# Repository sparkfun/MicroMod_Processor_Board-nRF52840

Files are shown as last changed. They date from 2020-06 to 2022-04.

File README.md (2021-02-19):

SparkFun MicroMod Processor - nRF52840
========================================

SparkFun MicroMod Processor - nRF52840 (https://www.sparkfun.com/products/16984)

[*SparkFun MicroMod Processor - nRF52840 (DEV-16984)*](https://www.sparkfun.com/products/16984)

Featuring the nRF52840 SoC from Nordic Semiconductor, the SparkFun MicroMod nRF52840 Processor offers a powerful combination of ARM Cortex-M4 CPU and 2.4 GHz Bluetooth transceiver in the MicroMod form-factor with the M.2 MicroMod connector to allow you to plug in a compatible MicroMod Carrier Board in the [MicroMod Ecosystem](https://www.sparkfun.com/micromod). 

The nRF52840 module includes a BT 5.1 stack and supports Bluetooth 5, Bluetooth mesh, IEEE 802.15.4 (Zigbee & Thread) and 2.4Ghz RF wireless protocols (including Nordic's proprietary RF protocol) allowing you to pick which option works best for your application. 

Repository Contents
-------------------

* **/Hardware** - Eagle design files (.brd, .sch)
* **/SF_MM_nRF52840_PB** - Board variant files for Arduino mbed Core.
* **/TestSketches** - Related software for the MicroMod nRF52840 Processor

Documentation
--------------

* **[Hookup Guide](https://learn.sparkfun.com/tutorials/micromod-nrf52840-processor-hookup-guide)** - Basic hookup guide for the MicroMod Processor - nRF52840.
* **[Getting Started with MicroMod](https://learn.sparkfun.com/tutorials/getting-started-with-micromod)** - A tutorial to help you get started with the MicroMod Ecosystem. 
* **[Designing with MicroMod](https://learn.sparkfun.com/tutorials/designing-with-micromod)** - A tutorial to walk you through the specs of the MicroMod processor and carrier board as well as the basics of incorporating the MicroMod form factor into your own PCB designs.
* **[SparkFun Graphical Datasheets](https://github.com/sparkfun/Graphical_Datasheets)** -Graphical Datasheets for various SparkFun products.

License Information
-------------------

This product is _**open source**_! 

Please review the LICENSE.md file for license information. 

If you have any questions or concerns on licensing, please contact technical support on our [SparkFun forums](https://forum.sparkfun.com/viewforum.php?f=152).

Distributed as-is; no warranty is given.

- Your friends at SparkFun.

_<COLLABORATION CREDIT>_

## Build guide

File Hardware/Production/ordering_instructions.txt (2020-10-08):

panel size, 194x70mm
PCB thickness, 0.8mm
number of layers, 4
soldermask color, Red
silkscreen color, White
oz copper, 1oz
finish, ENIG
stencils, top+bottom
pcs per panel, 16
min trace width, 0.1016mm / 0.0040in
min drill size, 0.2000mm / 0.0079in
filename to layer stackup 1/2/3/4: GTL, GL2, GL3, GBL

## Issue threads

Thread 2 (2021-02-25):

Fix ble_temp example

adamgarbo, 2021-02-25:
Hi folks,

A quick heads up that the "ble_temp" example is missing `Wire.begin();`. This prevents the I2C bus/BME280 from initializing and causes the code to freeze after the BLE is initialized. Once added, the code works as intended.

Related forum post: https://forum.sparkfun.com/viewtopic.php?f=182&t=55165

Cheers,
Adam

AndyEngland521, 2021-02-25:
Good catch @adamgarbo

Closed 2021-02-25.

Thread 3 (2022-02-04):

Arduino pin definition compatibility with MicroMod generic pin names

santaimpersonator, 2022-02-04:
Currently, the instructions in the hookup guide don't take into account for the generic pin names of the MicroMod system. For example, the pin names `G0` and  `D0` don't compile in the Arduino IDE.

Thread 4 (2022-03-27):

in correct boards.txt fot softfp

paulvha, 2022-03-27:
When compiling sketch like
```
void setup() {
  // put your setup code here, to run once:
  Serial.begin(115200);
  Serial.print("hallo");

}

void loop() {
  // put your main code here, to run repeatedly:

}
```

you get an error message :
```
arm-none-eabi-g++: error: softfp: No such file or directory
arm-none-eabi-g++: error: fpv4-sp-d16: No such file or directory
exit status 1
Error compiling for board SparkFun MicroMod nRF52840 Processor Board.
```
**Root cause on Mbed Arduino library 2.80, with the compiler arm-none-eabi-gcc-7-2017q4, is the incorrect definition for floating-point.**

You need to change in the boards.txt the definition from

```
sfnrf52840pb.build.fpu=fpv4-sp-d16
sfnrf52840pb.build.float-abi=softfp
```
to
```
sfnrf52840pb.build.fpu=-mfpu=fpv4-sp-d16
sfnrf52840pb.build.float-abi=-mfloat-abi=softfp
```
regards,
Paul

makin-stuff, 2022-04-07:
boards.txt and SF_MM_nRF52840_PB files updated.

Closed 2022-04-07.

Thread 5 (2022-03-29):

more changes needed to compile on version 3.0

paulvha, 2022-03-29:
Compiling the MM nRF52840 will fail on Arduino library version 3.0.

Not only the softfp errors, as mentioned in the other issue, but also other errors. This Sparkfun add-in for the MBED-nano library needs to be updated

see https://forum.sparkfun.com/viewtopic.php?f=182&t=57407&p=232189#p232189 for details and changes to be made

regards,
Paul

makin-stuff, 2022-03-29:
Hi there @paulvha. Thank you for updating us. I will look into these issues with the mbed core sometime this week.

paulvha, 2022-03-30:
Thanks. The issues are not caused by Mbed, They are caused by changes in the Arduino Library folder structure and new  paramaters.
regards,
Paul

makin-stuff, 2022-04-07:
Hi there @paulvha .

I've updated the boards.txt and SF_MM_nRF52840_PB files like you've outlined in the forum post to be compatible with the "Arduino Mbed OS Nano Boards" v3.0.1. I've tested these changes on my personal hardware.

 I'm closing this issue for now, but if you try these files out and they don't work for some reason, please open up another issue on this repo. I will work to get the documentation associated with this product updated as well.

Thanks!

Closed 2022-04-07.

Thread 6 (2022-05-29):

ArduinoBLE fails to compile on nrf52480

paulvha, 2022-05-29:
Based on a post on the SparkFun forum https://forum.sparkfun.com/viewtopic.php?f=182&t=57779, I looked into this problem.

**Error description**
Any ArduinoBLE example (e.g. Batterymonitor) will fail as it can not find references to certain routines.

C:\Users\hk\AppData\Local\Temp\arduino_build_501413\libraries\ArduinoBLE-1.2.2\utility\HCICordioTransport.cpp.o: In function `HCICordioTransportClass::end()':
C:\Users\hk\Documents\Arduino\libraries\ArduinoBLE-1.2.2\src\utility/HCICordioTransport.cpp:237: undefined reference to `ble::CordioHCIDriver::terminate()'
C:\Users\hk\AppData\Local\Temp\arduino_build_501413\libraries\ArduinoBLE-1.2.2\utility\HCICordioTransport.cpp.o: In function `HCICordioTransportClass::begin()':
C:\Users\hk\Documents\Arduino\libraries\ArduinoBLE-1.2.2\src\utility/HCICordioTransport.cpp:215: undefined reference to `ble::CordioHCIDriver::initialize()'
C:\Users\hk\Documents\Arduino\libraries\ArduinoBLE-1.2.2\src\utility/HCICordioTransport.cpp:69: undefined reference to `ble::CordioHCITransportDriver::set_data_received_handler(void (*)(unsigned char*, unsigned char))'

**Root cause**

The libmbed.a  that Sparkfun provides with the variant is using the OLD namespace definition for BLE. The BLE namespace has structure has changed starting Mbed 6.2.1. Arduino is using an Mbed 6 later version than 6.2.1

**Solution**

In the Mbed files in 6.2.0 or before:
CordioHCIDriver.cpp
CordioHCIDriver.h
CordioHCITransportDriver.h
CordioHCITransportDriver.cpp

These files are located  in the folder : mbed-os/features/FEATURE_BLE/targets/TARGET_CORDIO/driver

The namespace definition needs to be changed from :

```
namespace ble {
namespace vendor {
namespace cordio {
```
to

`namespace ble {`

Next to that it will need changes in different files for the nrf52480 Bluetooth target for using the right namespaces : e.g.

using namespace ble::vendor::ambiq_micro;
using namespace ble::vendor::cordio;

A new libmbed.a needs to be created and provided. This will apply to all the nrf52480 that are add-on to the Arduino Nano-Mbed.

Just a thought:
Given that Arduino is making regular changes to their Nano-mbed library and it is hard to keep up with that, wouldn't it be better to take the same approach as Artemis/Apollo3 and provide a single complete library package with Mbed where Sparkfun controls the all the changes?

regards,
Paul

makin-stuff, 2022-06-09:
Hi there @paulvha. Thank you for reporting this problem on our repo. Good catch with the Arduino boards update!

The libmbed.a file is a copy from the "ARDUINO_NANO33BLE" variant. We've updated the [hookup guide](https://learn.sparkfun.com/tutorials/micromod-nrf52840-processor-hookup-guide/arduino-software-setup) to advise customers to duplicate that folder, rename it, and then copy over the unique files from this repo (variant.cpp, pins_ardhuino.h, and boards.txt) in hopes that this would mitigate compilation errors as the arduino package gets updated.

Unfortunately, at this time there is no planned effort to support the MM nRF52840 PB in the same manner we support the Artemis module.

Thanks again for your time and effort!

Closed 2022-06-09.

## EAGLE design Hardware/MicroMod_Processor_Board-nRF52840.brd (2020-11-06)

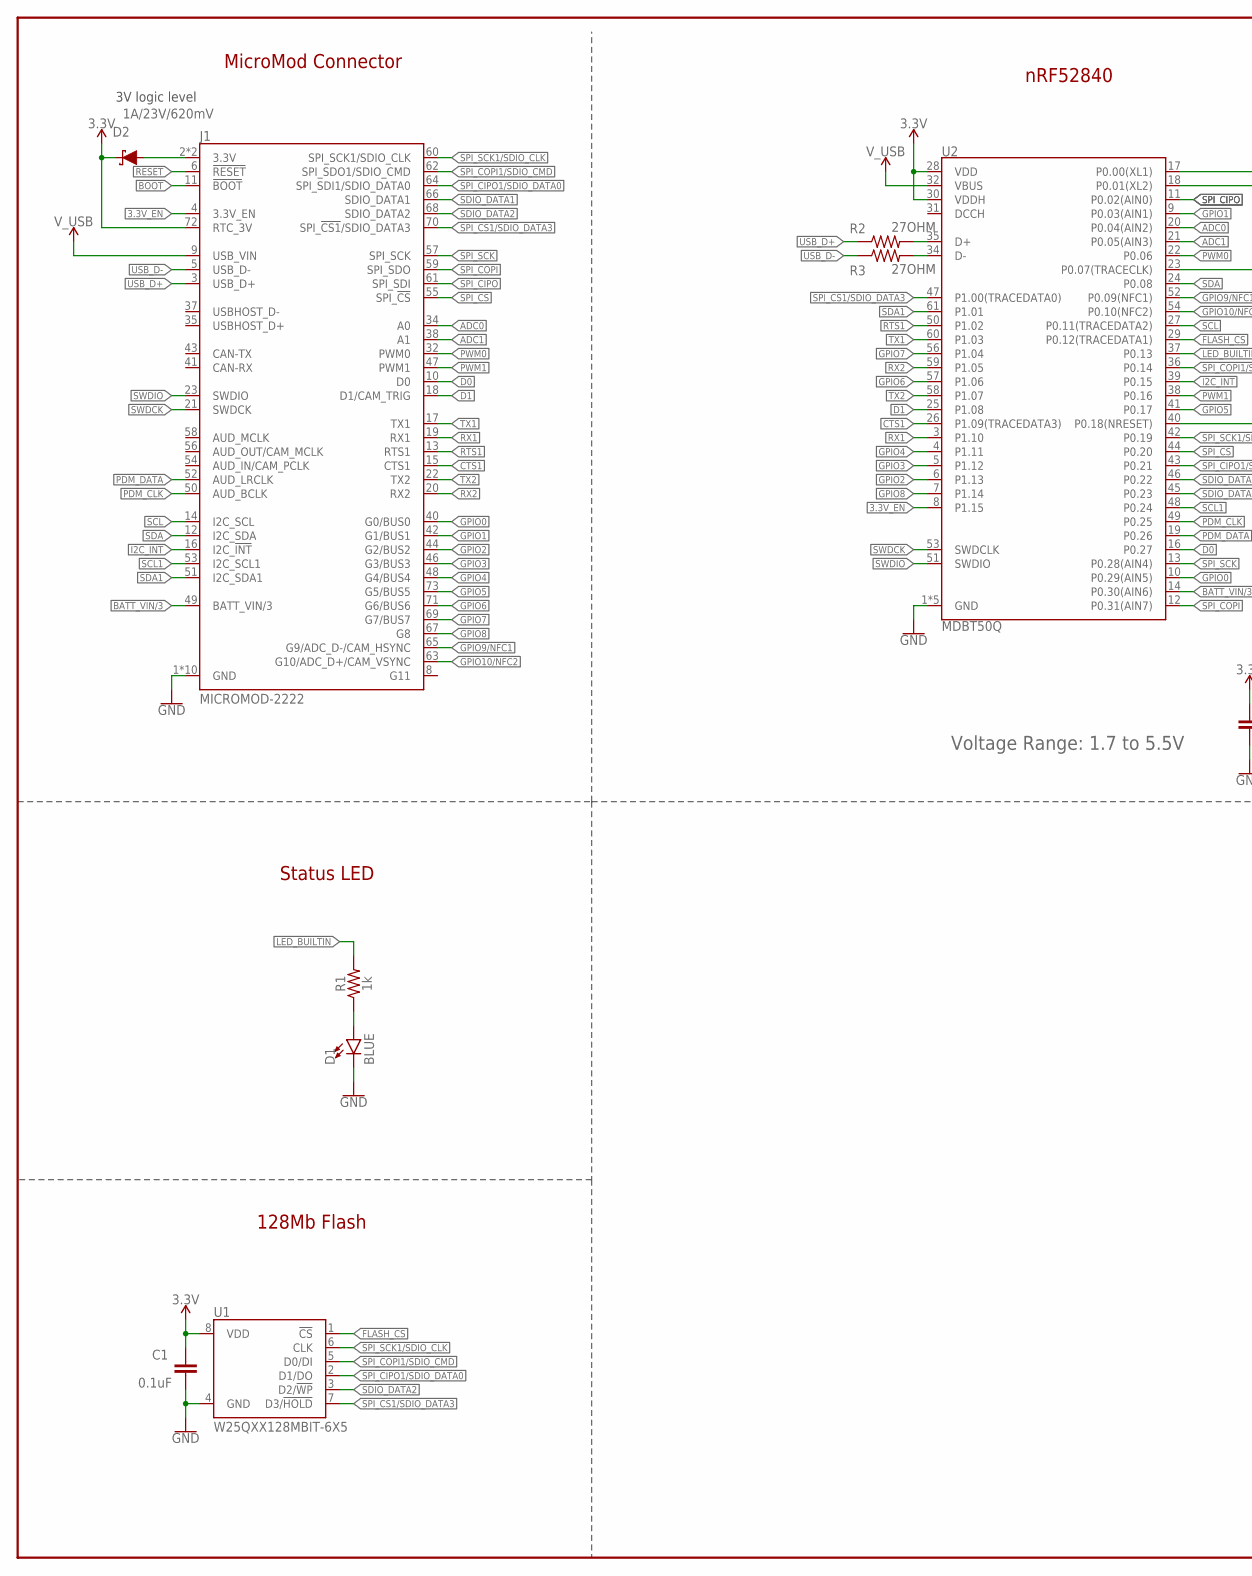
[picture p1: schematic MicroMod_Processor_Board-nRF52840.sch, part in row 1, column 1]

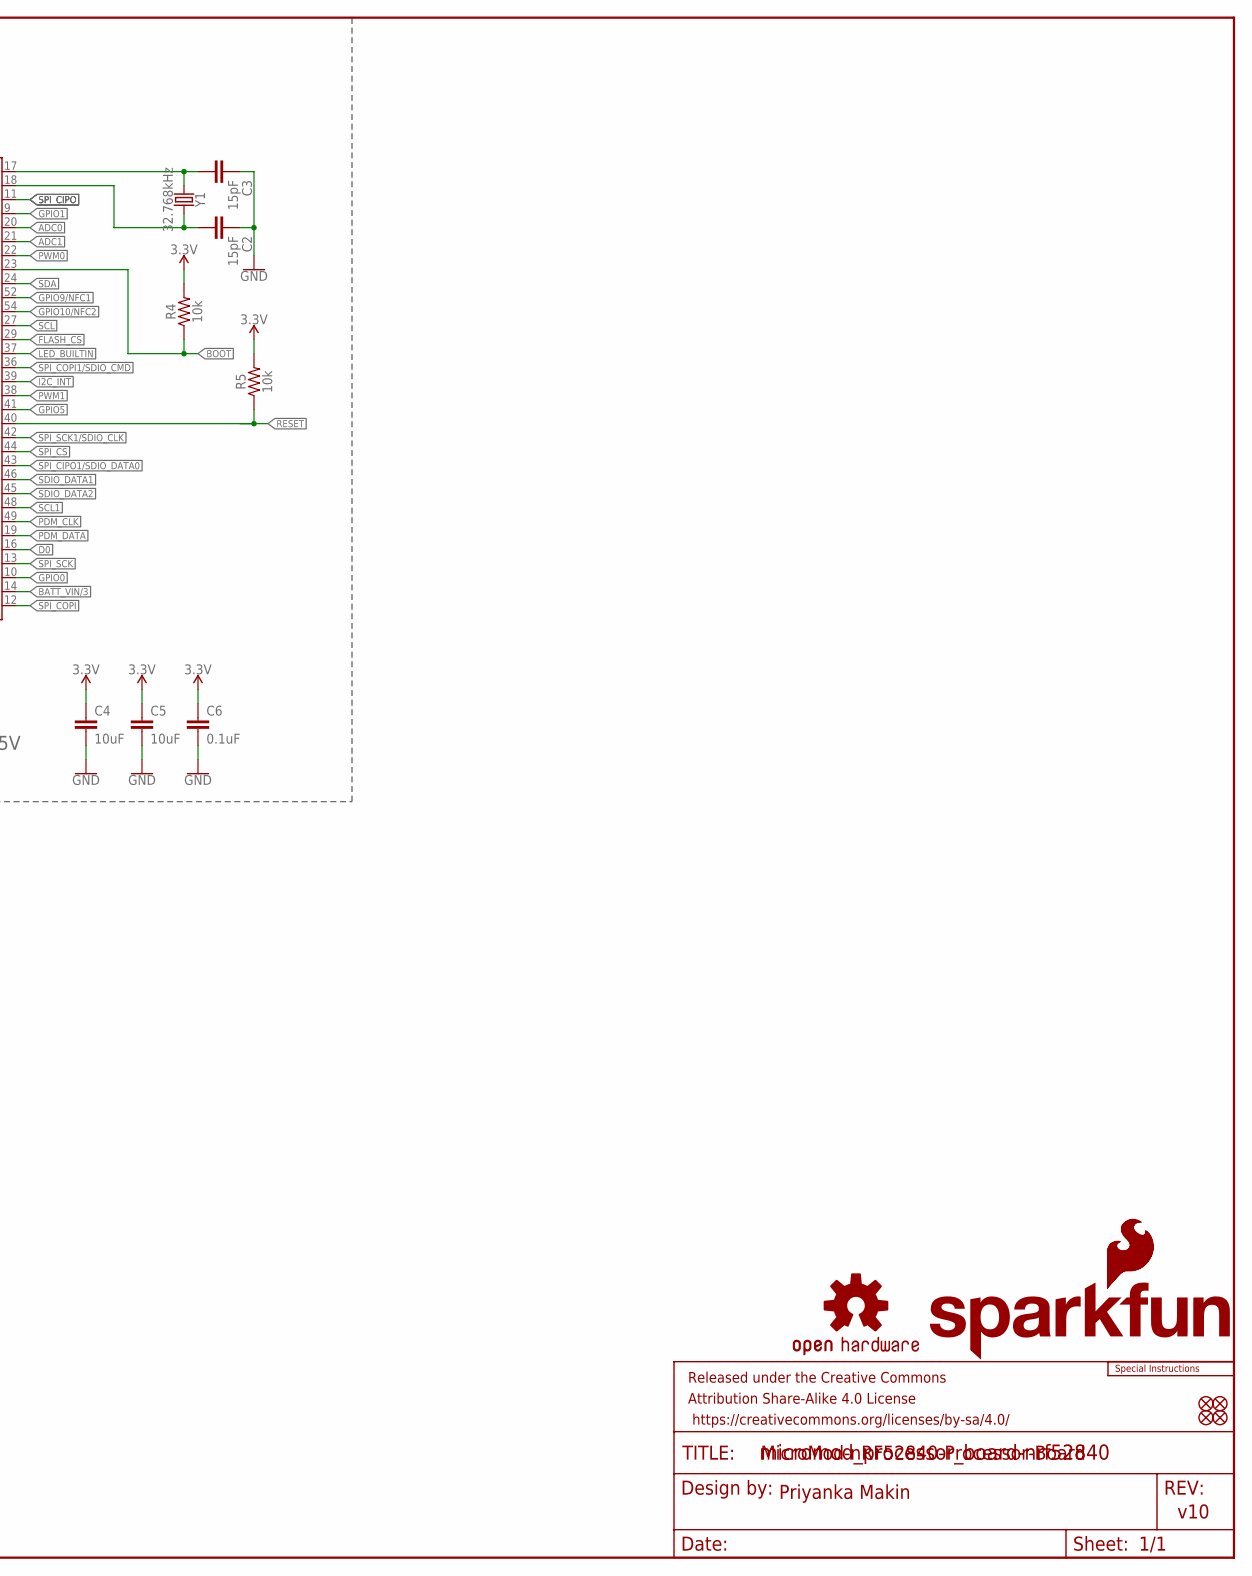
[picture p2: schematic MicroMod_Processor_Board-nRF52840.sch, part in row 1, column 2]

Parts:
C1, C6: 0.1uF; 0402-TIGHT
C2, C3: 15pF; 0402-TIGHT
C4, C5: 10uF; 0402-TIGHT
D1: BLUE; LED-0603
D2: 1A/23V/620mV; SOD-323
FD1, FD2, FD3, FD4: FIDUCIALUFIDUCIAL; FIDUCIAL-MICRO
FRAME1: FRAME-LEDGER; CREATIVE_COMMONS
J1: MICROMOD-2222; M.2-CARD-E-22
LOGO1: SFE_LOGO_NAME_FLAME.1_INCH; SFE_LOGO_NAME_FLAME_.1
LOGO2: SFE_LOGO_FLAME.1_INCH; SFE_LOGO_FLAME_.1
LOGO3: OSHW-LOGOMINI; OSHW-LOGO-MINI
LOGO4: SPECIAL_INSTRUCTIONS-ORDERING; ORDERING_INSTRUCTIONS
R1: 1k; 0402-TIGHT
R2, R3: 27OHM; 0402-TIGHT
R4, R5: 10k; 0402-TIGHT
U1: W25QXX128MBIT-6X5; WSON-8-6X5
U2: MDBT50Q
Y1: 32.768kHz; CRYSTAL-SMD-3.2X1.5MM

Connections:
3.3V: C1.1, C4.1, C5.1, C6.1, D2.C, J1.72 (RTC_3V), R4.2, R5.2, U1.8 (VDD), U2.28 (VDD), U2.30 (VDDH)
3.3V_EN: J1.4 (3.3V_EN), U2.8 (P1.15)
!BOOT!: J1.11 (!BOOT!), R4.1, U2.23 (P0.07(TRACECLK))
!RESET!: J1.6 (!RESET!), R5.1, U2.40 (P0.18(NRESET))
ADC0: J1.34 (A0), U2.20 (P0.04(AIN2))
ADC1: J1.38 (A1), U2.21 (P0.05(AIN3))
BATT_VIN/3: J1.49 (BATT_VIN/3), U2.14 (P0.30(AIN6))
CTS1: J1.15 (CTS1), U2.26 (P1.09(TRACEDATA3))
D0: J1.10 (D0), U2.16 (P0.27)
D1: J1.18 (D1/CAM_TRIG), U2.25 (P1.08)
FLASH_!CS!: U1.1 (!CS!), U2.29 (P0.12(TRACEDATA1))
GND: C1.2, C2.1, C3.1, C4.2, C5.2, C6.2, D1.C, J1.1 (GND), J1.7 (GND), J1.33 (GND), J1.36 (GND), J1.39 (GND), J1.45 (GND), J1.75 (GND), J1.GND1 (GND), J1.GND2 (GND), J1.GND3 (GND), U1.4 (GND), U2.1 (GND), U2.2 (GND), U2.15 (GND), U2.33 (GND), U2.55 (GND)
GPIO0: J1.40 (G0/BUS0), U2.10 (P0.29(AIN5))
GPIO1: J1.42 (G1/BUS1), U2.9 (P0.03(AIN1))
GPIO2: J1.44 (G2/BUS2), U2.6 (P1.13)
GPIO3: J1.46 (G3/BUS3), U2.5 (P1.12)
GPIO4: J1.48 (G4/BUS4), U2.4 (P1.11)
GPIO5: J1.73 (G5/BUS5), U2.41 (P0.17)
GPIO6: J1.71 (G6/BUS6), U2.57 (P1.06)
GPIO7: J1.69 (G7/BUS7), U2.56 (P1.04)
GPIO8: J1.67 (G8), U2.7 (P1.14)
GPIO9/NFC1: J1.65 (G9/ADC_D-/CAM_HSYNC), U2.52 (P0.09(NFC1))
GPIO10/NFC2: J1.63 (G10/ADC_D+/CAM_VSYNC), U2.54 (P0.10(NFC2))
I2C_!INT!: J1.16 (I2C_!INT!), U2.39 (P0.15)
LED_BUILTIN: R1.2, U2.37 (P0.13)
unnamed: R2.2, U2.35 (D+)
unnamed: D1.A, R1.1
unnamed: R3.2, U2.34 (D-)
unnamed: C3.2, U2.17 (P0.00(XL1)), Y1.P$1 (1)
unnamed: D2.A, J1.2 (3.3V), J1.74 (3.3V)
unnamed: C2.2, U2.18 (P0.01(XL2)), Y1.P$2 (2)
PDM_CLK: J1.50 (AUD_BCLK), U2.49 (P0.25)
PDM_DATA: J1.52 (AUD_LRCLK), U2.19 (P0.26)
PWM0: J1.32 (PWM0), U2.22 (P0.06)
PWM1: J1.47 (PWM1), U2.38 (P0.16)
RTS1: J1.13 (RTS1), U2.50 (P1.02)
RX1: J1.19 (RX1), U2.3 (P1.10)
RX2: J1.20 (RX2), U2.59 (P1.05)
SCL: J1.14 (I2C_SCL), U2.27 (P0.11(TRACEDATA2))
SCL1: J1.53 (I2C_SCL1), U2.48 (P0.24)
SDA: J1.12 (I2C_SDA), U2.24 (P0.08)
SDA1: J1.51 (I2C_SDA1), U2.61 (P1.01)
SDIO_DATA1: J1.66 (SDIO_DATA1), U2.46 (P0.22)
SDIO_DATA2: J1.68 (SDIO_DATA2), U1.3 (D2/!WP!), U2.45 (P0.23)
SPI_!CS1!/SDIO_DATA3: J1.70 (SPI_!CS1!/SDIO_DATA3), U1.7 (D3/!HOLD!), U2.47 (P1.00(TRACEDATA0))
SPI_!CS!: J1.55 (SPI_!CS!), U2.44 (P0.20)
SPI_CIPO: J1.61 (SPI_SDI), U2.11 (P0.02(AIN0))
SPI_CIPO1/SDIO_DATA0: J1.64 (SPI_SDI1/SDIO_DATA0), U1.2 (D1/DO), U2.43 (P0.21)
SPI_COPI: J1.59 (SPI_SDO), U2.12 (P0.31(AIN7))
SPI_COPI1/SDIO_CMD: J1.62 (SPI_SDO1/SDIO_CMD), U1.5 (D0/DI), U2.36 (P0.14)
SPI_SCK: J1.57 (SPI_SCK), U2.13 (P0.28(AIN4))
SPI_SCK1/SDIO_CLK: J1.60 (SPI_SCK1/SDIO_CLK), U1.6 (CLK), U2.42 (P0.19)
SWDCK: J1.21 (SWDCK), U2.53 (SWDCLK)
SWDIO: J1.23 (SWDIO), U2.51 (SWDIO)
TX1: J1.17 (TX1), U2.60 (P1.03)
TX2: J1.22 (TX2), U2.58 (P1.07)
USB_D+: J1.3 (USB_D+), R2.1
USB_D-: J1.5 (USB_D-), R3.1
V_USB: J1.9 (USB_VIN), U2.32 (VBUS)

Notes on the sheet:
MicroMod Connector
Status LED
MicroMod-nRF52840-Processor-Board
Priyanka Makin
v10
128Mb Flash
Voltage Range: 1.7 to 5.5V
nRF52840
3V logic level

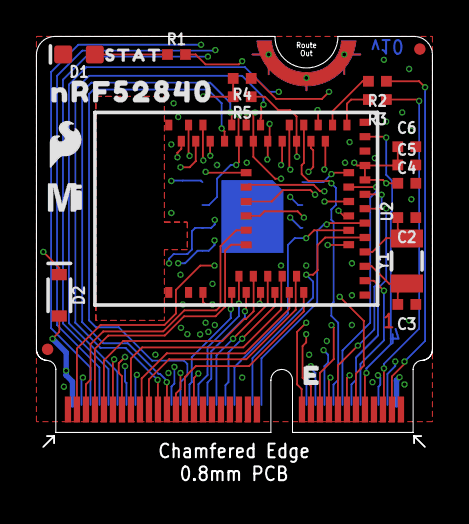
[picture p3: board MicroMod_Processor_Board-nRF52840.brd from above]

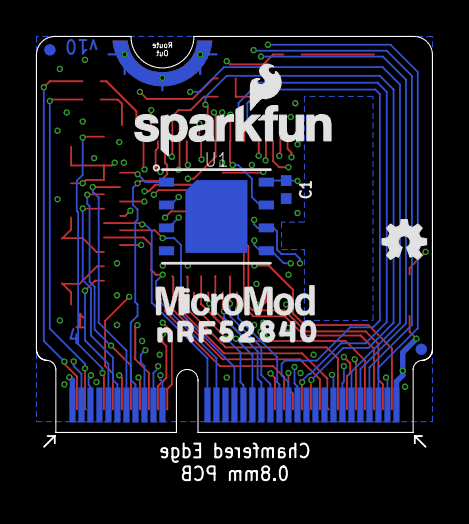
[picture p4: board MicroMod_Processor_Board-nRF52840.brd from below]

Board: 4 copper layers, 22.0 x 22.8 mm, 31 parts (8 on the bottom side), 59 nets.

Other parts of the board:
U$1: MICROMOD_MI_LOGO_.35
U$2: STAT0
U$3, U$6: NRF528400
U$5: MICROMOD_LOGO_.35

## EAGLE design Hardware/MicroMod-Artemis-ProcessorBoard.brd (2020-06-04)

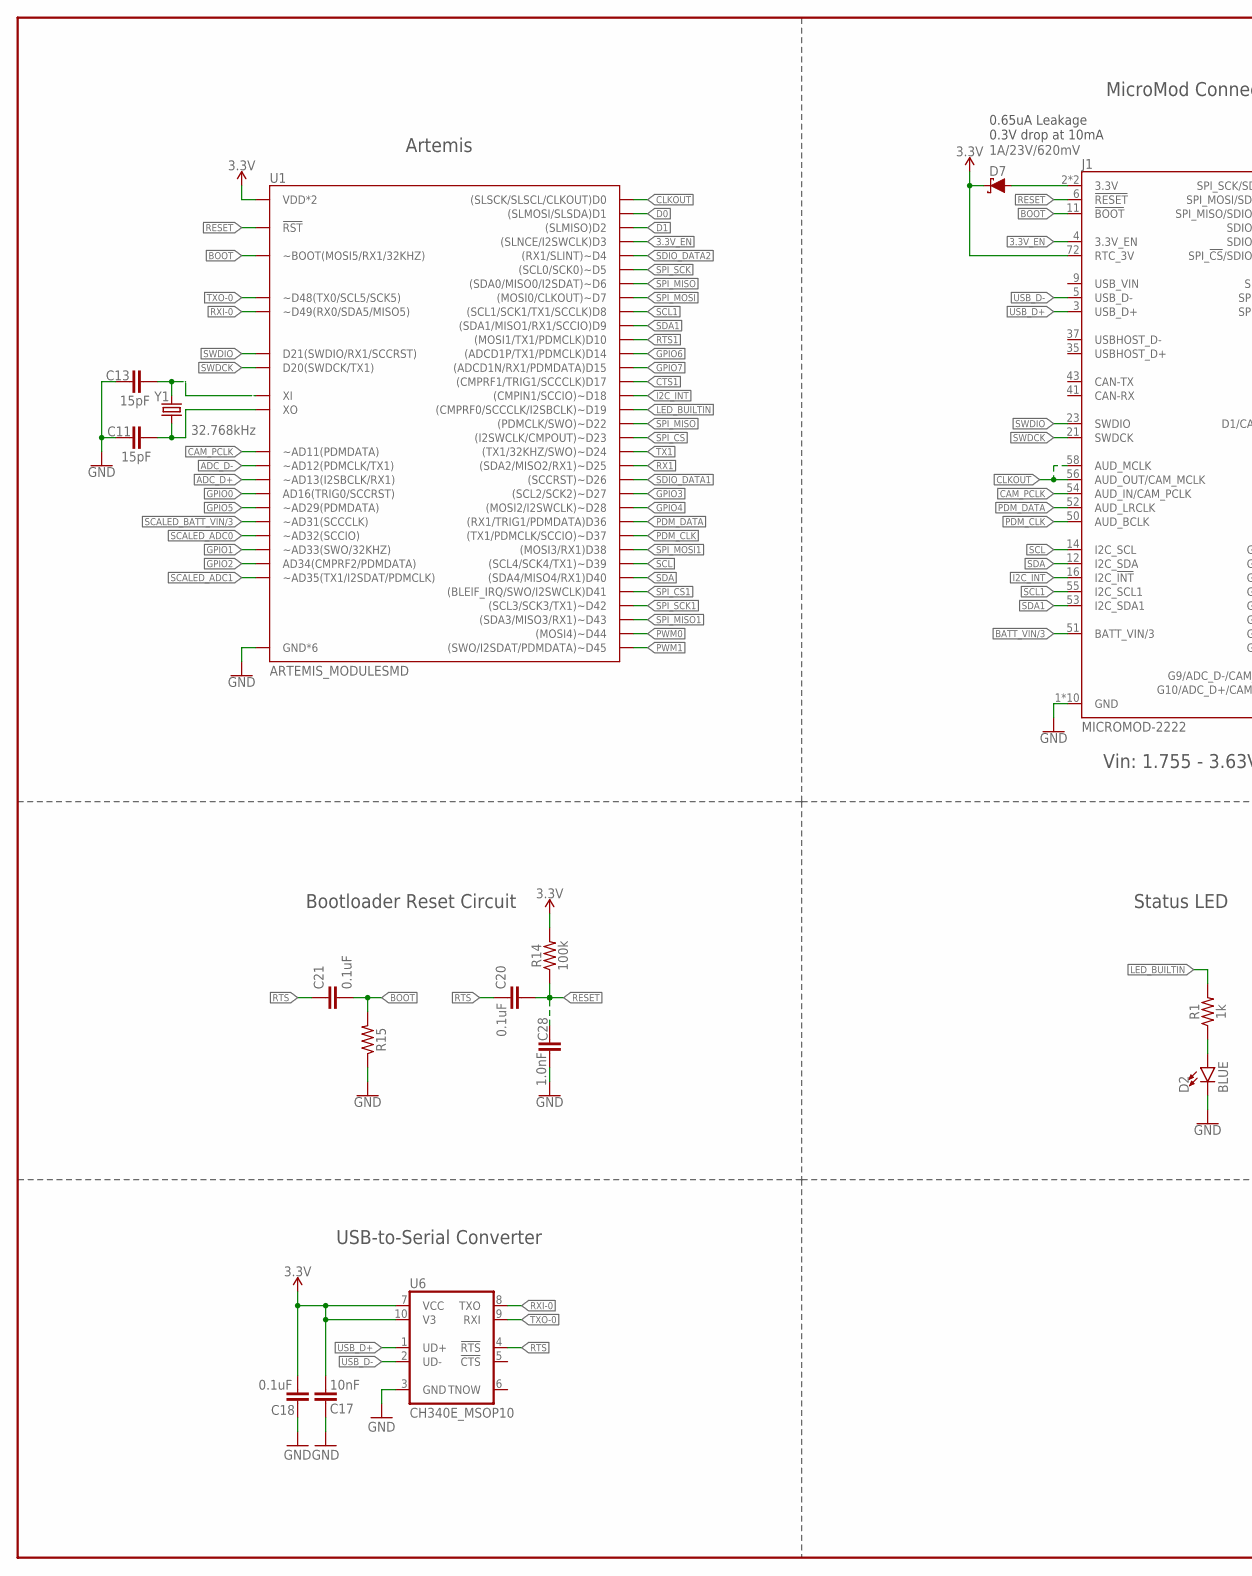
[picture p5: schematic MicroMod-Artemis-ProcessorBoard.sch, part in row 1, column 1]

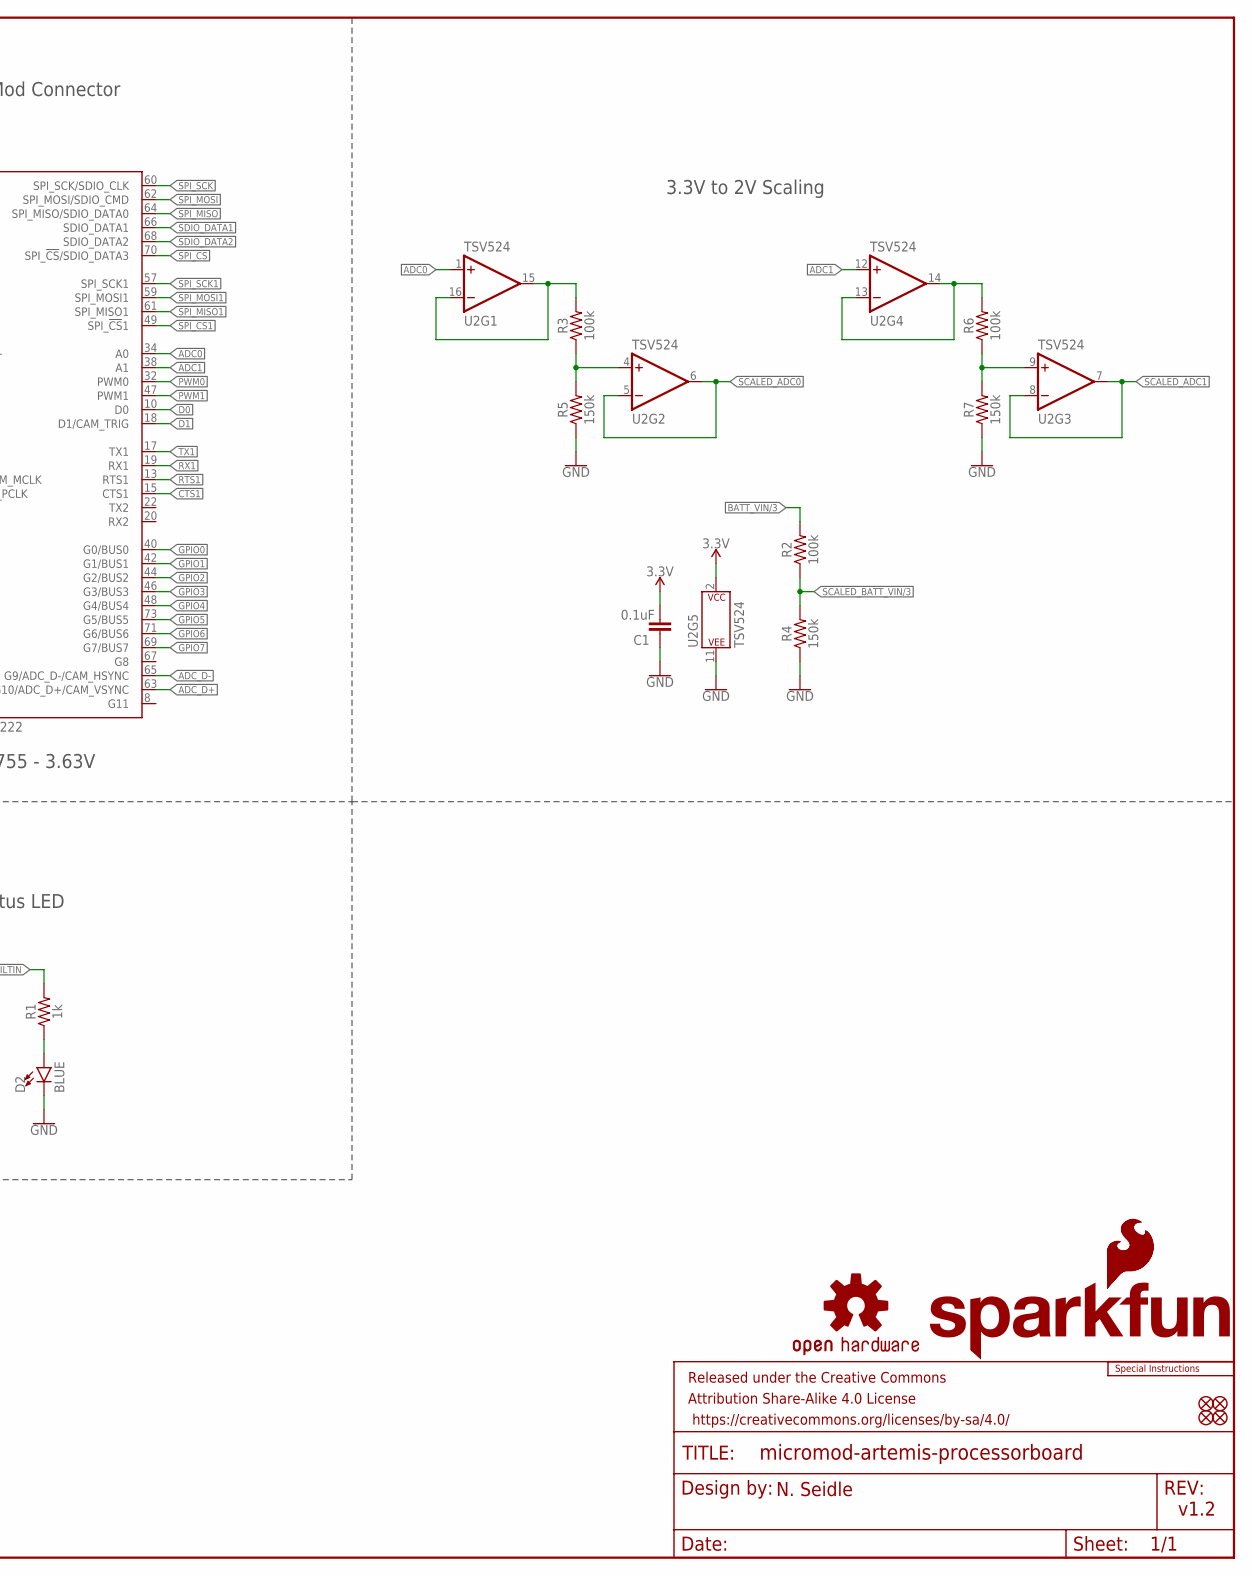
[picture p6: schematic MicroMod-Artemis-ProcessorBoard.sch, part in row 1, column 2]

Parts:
C1, C18, C20, C21: 0.1uF; 0402-TIGHT
C11, C13: 15pF; 0402-TIGHT
C17: 10nF; 0402-TIGHT
C28: 1.0nF; 0402-TIGHT
D2: BLUE; LED-0603
D7: 1A/23V/620mV; SOD-323
FD1, FD2, FD3, FD4: FIDUCIALUFIDUCIAL; FIDUCIAL-MICRO
FRAME1: FRAME-LEDGER; CREATIVE_COMMONS
J1: MICROMOD-2222; M.2-CARD-E-22
LOGO1: SFE_LOGO_NAME_FLAME.1_INCH; SFE_LOGO_NAME_FLAME_.1
LOGO2: SFE_LOGO_FLAME.1_INCH; SFE_LOGO_FLAME_.1
LOGO3: OSHW-LOGOMINI; OSHW-LOGO-MINI
LOGO4: SPECIAL_INSTRUCTIONS-ORDERING; ORDERING_INSTRUCTIONS
R1: 1k; 0402-TIGHT
R2, R3, R6, R14: 100k; 0402-TIGHT
R4, R5, R7: 150k; 0402-TIGHT
R15: 220KOHM-0402T-1/16W-1%; 0402-TIGHT
U1: ARTEMIS_MODULESMD; ARTEMIS_FP
U2: TSV524; QFN-16
U6: CH340E_MSOP10; MSOP10
Y1: 32.768kHz; CRYSTAL-SMD-3.2X1.5MM

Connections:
3.3V: C1.1, C17.1, C18.1, D7.C, J1.72 (RTC_3V), R14.2, U1.VDD@36 (VDD*2), U1.VDD@37 (VDD*2), U2.2 (V+), U6.7 (VCC), U6.10 (V3)
3.3V_EN: J1.4 (3.3V_EN), U1.D3 ((SLNCE/I2SWCLK)D3)
3.3V_MAIN: D7.A, J1.2 (3.3V), J1.74 (3.3V)
!RESET!: C20.2, C28.1, J1.6 (!RESET!), R14.1, U1.~RST (!RST)
!RTS: C20.1, C21.1, U6.4 (!RTS)
ADC0: J1.34 (A0), U2.1 (+IN)
ADC0_BUFF1: R3.2, U2.15 (OUT), U2.16 (-IN)
ADC0_BUFF2: R3.1, R5.2, U2.4 (+IN)
ADC1: J1.38 (A1), U2.12 (+IN)
ADC1_BUFF2: R6.1, R7.2, U2.9 (+IN)
ADC_BUFF1: R6.2, U2.13 (-IN), U2.14 (OUT)
ADC_D+: J1.63 (G10/ADC_D+/CAM_VSYNC), U1.~AD13 (~AD13(I2SBCLK/RX1))
ADC_D-: J1.65 (G9/ADC_D-/CAM_HSYNC), U1.~AD12 (~AD12(PDMCLK/TX1))
BATT_VIN/3: J1.51 (BATT_VIN/3), R2.2
BOOT: C21.2, J1.11 (!BOOT!), R15.2, U1.BOOT (~BOOT(MOSI5/RX1/32KHZ))
CAM_PCLK: J1.54 (AUD_IN/CAM_PCLK), U1.~AD11 (~AD11(PDMDATA))
CLKOUT: J1.56 (AUD_OUT/CAM_MCLK), J1.58 (AUD_MCLK), U1.D0 ((SLSCK/SLSCL/CLKOUT)D0)
CTS1: J1.15 (CTS1), U1.D17 ((CMPRF1/TRIG1/SCCCLK)D17)
D0: J1.10 (D0), U1.D1 ((SLMOSI/SLSDA)D1)
D1: J1.18 (D1/CAM_TRIG), U1.D2 ((SLMISO)D2)
GND: C1.2, C11.1, C13.1, C17.2, C18.2, C28.2, D2.C, J1.1 (GND), J1.7 (GND), J1.33 (GND), J1.36 (GND), J1.39 (GND), J1.45 (GND), J1.75 (GND), J1.GND1 (GND), J1.GND2 (GND), J1.GND3 (GND), R4.1, R5.1, R7.1, R15.1, U1.GND@1 (GND*6), U1.GND@22 (GND*6), U1.GND@38 (GND*6), U1.GND@39 (GND*6), U1.GND@47 (GND*6), U1.GND@59 (GND*6), U2.11 (V-), U6.3 (GND)
GPIO0: J1.40 (G0/BUS0), U1.AD16 (AD16(TRIG0/SCCRST))
GPIO1: J1.42 (G1/BUS1), U1.~AD33/SWO (~AD33(SWO/32KHZ))
GPIO2: J1.44 (G2/BUS2), U1.AD34 (AD34(CMPRF2/PDMDATA))
GPIO3: J1.46 (G3/BUS3), U1.~D27 ((SCL2/SCK2)~D27)
GPIO4: J1.48 (G4/BUS4), U1.~D28 ((MOSI2/I2SWCLK)~D28)
GPIO5: J1.73 (G5/BUS5), U1.~AD29 (~AD29(PDMDATA))
GPIO6: J1.71 (G6/BUS6), U1.D14 ((ADCD1P/TX1/PDMCLK)D14)
GPIO7: J1.69 (G7/BUS7), U1.D15 ((ADCD1N/RX1/PDMDATA)D15)
I2C_!INT!: J1.16 (I2C_!INT!), U1.~D18 ((CMPIN1/SCCIO)~D18)
LED_BUILTIN: R1.2, U1.~D19 ((CMPRF0/SCCCLK/I2SBCLK)~D19)
unnamed: D2.A, R1.1
unnamed: C13.2, Y1.P$1 (1)
unnamed: C11.2, U1.XO, Y1.P$2 (2)
PDM_CLK: J1.50 (AUD_BCLK), U1.~D37 ((TX1/PDMCLK/SCCIO)~D37)
PDM_DATA: J1.52 (AUD_LRCLK), U1.D36 ((RX1/TRIG1/PDMDATA)D36)
PWM0: J1.32 (PWM0), U1.~D44 ((MOSI4)~D44)
PWM1: J1.47 (PWM1), U1.~D45 ((SWO/I2SDAT/PDMDATA)~D45)
RTS1: J1.13 (RTS1), U1.D10 ((MOSI1/TX1/PDMCLK)D10)
RX1: J1.19 (RX1), U1.~D25 ((SDA2/MISO2/RX1)~D25)
RXI-0: U1.RXI-0 (~D49(RX0/SDA5/MISO5)), U6.8 (TXO)
SCALED_ADC0: U1.~AD32 (~AD32(SCCIO)), U2.5 (-IN), U2.6 (OUT)
SCALED_ADC1: U1.~AD35 (~AD35(TX1/I2SDAT/PDMCLK)), U2.7 (OUT), U2.8 (-IN)
SCALED_BATT_VIN/3: R2.1, R4.2, U1.~AD31 (~AD31(SCCCLK))
SCL: J1.14 (I2C_SCL), U1.~D39 ((SCL4/SCK4/TX1)~D39)
SCL1: J1.55 (I2C_SCL1), U1.D8 ((SCL1/SCK1/TX1/SCCLK)D8)
SDA: J1.12 (I2C_SDA), U1.D40 ((SDA4/MISO4/RX1)D40)
SDA1: J1.53 (I2C_SDA1), U1.D9 ((SDA1/MISO1/RX1/SCCIO)D9)
SDIO_DATA1: J1.66 (SDIO_DATA1), U1.~D26 ((SCCRST)~D26)
SDIO_DATA2: J1.68 (SDIO_DATA2), U1.~D4 ((RX1/SLINT)~D4)
SPI_!CS!: J1.70 (SPI_!CS!/SDIO_DATA3), U1.~D23 ((I2SWCLK/CMPOUT)~D23)
SPI_!CS!1: J1.49 (SPI_!CS!1), U1.D41 ((BLEIF_IRQ/SWO/I2SWCLK)D41)
SPI_MISO: J1.64 (SPI_MISO/SDIO_DATA0), U1.~D6 ((SDA0/MISO0/I2SDAT)~D6), U1.~D22 ((PDMCLK/SWO)~D22)
SPI_MISO1: J1.61 (SPI_MISO1), U1.~D43 ((SDA3/MISO3/RX1)~D43)
SPI_MOSI: J1.62 (SPI_MOSI/SDIO_CMD), U1.D7 ((MOSI0/CLKOUT)~D7)
SPI_MOSI1: J1.59 (SPI_MOSI1), U1.D38 ((MOSI3/RX1)D38)
SPI_SCK: J1.60 (SPI_SCK/SDIO_CLK), U1.~D5 ((SCL0/SCK0)~D5)
SPI_SCK1: J1.57 (SPI_SCK1), U1.~D42 ((SCL3/SCK3/TX1)~D42)
SWDCK: J1.21 (SWDCK), U1.SWDCK (D20(SWDCK/TX1))
SWDIO: J1.23 (SWDIO), U1.SWDIO (D21(SWDIO/RX1/SCCRST))
TX1: J1.17 (TX1), U1.~D24 ((TX1/32KHZ/SWO)~D24)
TXO-0: U1.TXO-0 (~D48(TX0/SCL5/SCK5)), U6.9 (RXI)
USB_D+: J1.3 (USB_D+), U6.1 (UD+)
USB_D-: J1.5 (USB_D-), U6.2 (UD-)

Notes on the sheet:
USB-to-Serial Converter
Bootloader Reset Circuit
MicroMod Connector
3.3V to 2V Scaling
v1.2
N. Seidle
Artemis
Status LED
Vin: 1.755 - 3.63V
0.65uA Leakage 0.3V drop at 10mA

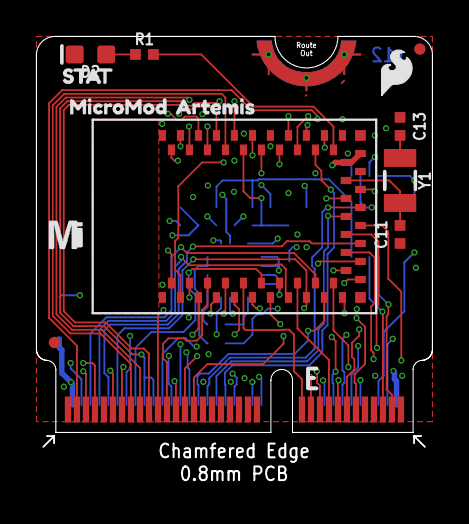
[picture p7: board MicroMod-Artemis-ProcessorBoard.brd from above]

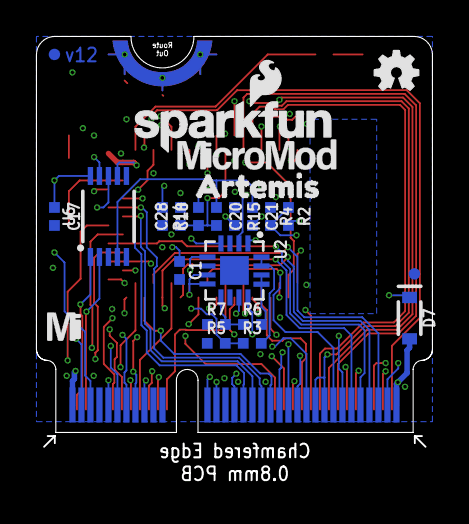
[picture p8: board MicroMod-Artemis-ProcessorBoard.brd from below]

Board: 4 copper layers, 22.0 x 22.8 mm, 40 parts (24 on the bottom side), 64 nets.

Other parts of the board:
U$1, U$7: MICROMOD_MI_LOGO_.35
U$2: ARTEMIS0
U$3: MICROMOD1
U$4: STAT_TO_32
U$5: MICROMOD_LOGO_.35
U$6: ARTEMIS2

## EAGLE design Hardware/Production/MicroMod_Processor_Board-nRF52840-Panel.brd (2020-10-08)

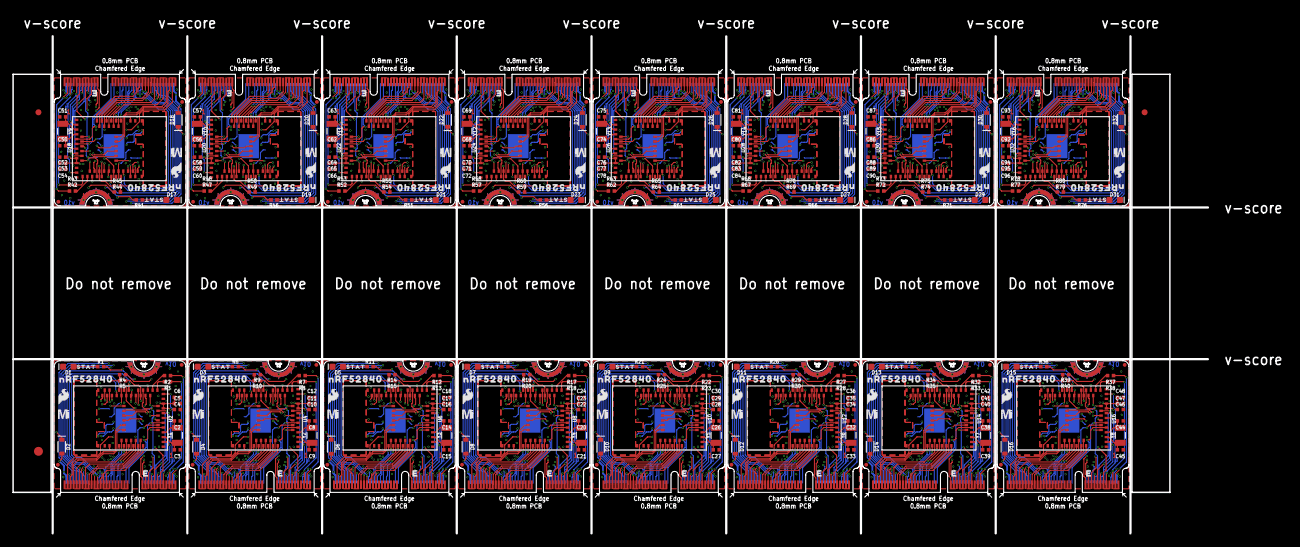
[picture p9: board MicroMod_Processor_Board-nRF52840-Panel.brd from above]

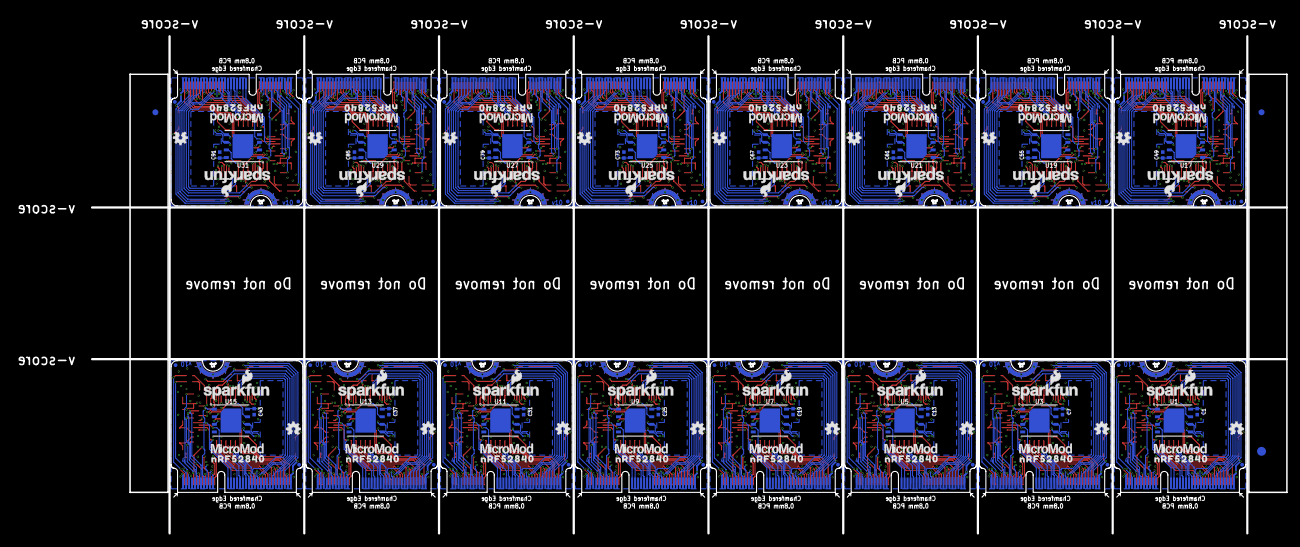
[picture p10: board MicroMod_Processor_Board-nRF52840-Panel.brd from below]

Board: 4 copper layers, 199.6 x 83.1 mm, 470 parts (131 on the bottom side), 944 nets.

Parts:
C1, C6, C7, C12, C13, C18, C19, C24, C25, C30, C31, C36, C37, C42, C43, C48, C49, C54, C55, C60, C61, C66, C67, C72, C73, C78, C79, C84, C85, C90, C91, C96: 0.1uF; 0402-TIGHT
C2, C3, C8, C9, C14, C15, C20, C21, C26, C27, C32, C33, C38, C39, C44, C45, C50, C51, C56, C57, C62, C63, C68, C69, C74, C75, C80, C81, C86, C87, C92, C93: 15pF; 0402-TIGHT
C4, C5, C10, C11, C16, C17, C22, C23, C28, C29, C34, C35, C40, C41, C46, C47, C52, C53, C58, C59, C64, C65, C70, C71, C76, C77, C82, C83, C88, C89, C94, C95: 10uF; 0402-TIGHT
D1, D3, D5, D7, D9, D11, D13, D15, D17, D19, D21, D23, D25, D27, D29, D31: BLUE; LED-0603
D2, D4, D6, D8, D10, D12, D14, D16, D18, D20, D22, D24, D26, D28, D30, D32: 1A/23V/620mV; SOD-323
E$1, E$2, E$3, E$4: FIDUCIAL-1X2
E$5, E$6: FIDUCIAL-1.5X3
FD1, FD2, FD3, FD4, FD5, FD6, FD7, FD8, FD9, FD10, FD11, FD12, FD13, FD14, FD15, FD16, FD17, FD18, FD19, FD20, FD21, FD22, FD23, FD24, FD25, FD26, FD27, FD28, FD29, FD30, FD31, FD32, FD33, FD34, FD35, FD36, FD37, FD38, FD39, FD40, FD41, FD42, FD43, FD44, FD45, FD46, FD47, FD48, FD49, FD50, FD51, FD52, FD53, FD54, FD55, FD56, FD57, FD58, FD59, FD60, FD61, FD62, FD63, FD64: FIDUCIALUFIDUCIAL; FIDUCIAL-MICRO
J1, J2, J3, J4, J5, J6, J7, J8, J9, J10, J11, J12, J13, J14, J15, J16: MICROMOD-2222; M.2-CARD-E-22
LOGO1, LOGO5, LOGO8, LOGO11, LOGO14, LOGO17, LOGO20, LOGO23, LOGO26, LOGO29, LOGO32, LOGO35, LOGO38, LOGO41, LOGO44, LOGO47: SFE_LOGO_NAME_FLAME.1_INCH; SFE_LOGO_NAME_FLAME_.1
LOGO2, LOGO6, LOGO9, LOGO12, LOGO15, LOGO18, LOGO21, LOGO24, LOGO27, LOGO30, LOGO33, LOGO36, LOGO39, LOGO42, LOGO45, LOGO48: SFE_LOGO_FLAME.1_INCH; SFE_LOGO_FLAME_.1
LOGO3, LOGO4, LOGO7, LOGO10, LOGO13, LOGO16, LOGO19, LOGO22, LOGO25, LOGO28, LOGO31, LOGO34, LOGO37, LOGO40, LOGO43, LOGO46: OSHW-LOGOMINI; OSHW-LOGO-MINI
R1, R6, R11, R16, R21, R26, R31, R36, R41, R46, R51, R56, R61, R66, R71, R76: 1k; 0402-TIGHT
R2, R3, R7, R8, R12, R13, R17, R18, R22, R23, R27, R28, R32, R33, R37, R38, R42, R43, R47, R48, R52, R53, R57, R58, R62, R63, R67, R68, R72, R73, R77, R78: 27OHM; 0402-TIGHT
R4, R5, R9, R10, R14, R15, R19, R20, R24, R25, R29, R30, R34, R35, R39, R40, R44, R45, R49, R50, R54, R55, R59, R60, R64, R65, R69, R70, R74, R75, R79, R80: 10k; 0402-TIGHT
U1, U3, U5, U7, U9, U11, U13, U15, U17, U19, U21, U23, U25, U27, U29, U31: W25QXX128MBIT-6X5; WSON-8-6X5
U2, U4, U6, U8, U10, U12, U14, U16, U18, U20, U22, U24, U26, U28, U30, U32: MDBT50Q
U$1, U$4, U$11, U$16, U$21, U$26, U$31, U$36, U$41, U$46, U$51, U$56, U$61, U$66, U$71, U$76: MICROMOD_MI_LOGO_.35
U$2, U$10, U$15, U$20, U$25, U$30, U$35, U$40, U$45, U$50, U$55, U$60, U$65, U$70, U$75, U$80: STAT0
U$3, U$6, U$8, U$9, U$13, U$14, U$18, U$19, U$23, U$24, U$28, U$29, U$33, U$34, U$38, U$39, U$43, U$44, U$48, U$49, U$53, U$54, U$58, U$59, U$63, U$64, U$68, U$69, U$73, U$74, U$78, U$79: NRF528400
U$5, U$7, U$12, U$17, U$22, U$27, U$32, U$37, U$42, U$47, U$52, U$57, U$62, U$67, U$72, U$77: MICROMOD_LOGO_.35
Y1, Y2, Y3, Y4, Y5, Y6, Y7, Y8, Y9, Y10, Y11, Y12, Y13, Y14, Y15, Y16: 32.768kHz; CRYSTAL-SMD-3.2X1.5MM

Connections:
3.3V: C1.1, C4.1, C5.1, C6.1, D2.C, J1.72, R4.2, R5.2, U1.8, U2.28, U2.30
3.3V1: C7.1, C10.1, C11.1, C12.1, D4.C, J2.72, R9.2, R10.2, U3.8, U4.28, U4.30
3.3V2: C13.1, C16.1, C17.1, C18.1, D6.C, J3.72, R14.2, R15.2, U5.8, U6.28, U6.30
3.3V3: C19.1, C22.1, C23.1, C24.1, D8.C, J4.72, R19.2, R20.2, U7.8, U8.28, U8.30
3.3V4: C25.1, C28.1, C29.1, C30.1, D10.C, J5.72, R24.2, R25.2, U9.8, U10.28, U10.30
3.3V5: C31.1, C34.1, C35.1, C36.1, D12.C, J6.72, R29.2, R30.2, U11.8, U12.28, U12.30
3.3V6: C37.1, C40.1, C41.1, C42.1, D14.C, J7.72, R34.2, R35.2, U13.8, U14.28, U14.30
3.3V7: C43.1, C46.1, C47.1, C48.1, D16.C, J8.72, R39.2, R40.2, U15.8, U16.28, U16.30
3.3V8: C49.1, C52.1, C53.1, C54.1, D18.C, J9.72, R44.2, R45.2, U17.8, U18.28, U18.30
3.3V9: C55.1, C58.1, C59.1, C60.1, D20.C, J10.72, R49.2, R50.2, U19.8, U20.28, U20.30
3.3V10: C61.1, C64.1, C65.1, C66.1, D22.C, J11.72, R54.2, R55.2, U21.8, U22.28, U22.30
3.3V11: C67.1, C70.1, C71.1, C72.1, D24.C, J12.72, R59.2, R60.2, U23.8, U24.28, U24.30
3.3V12: C73.1, C76.1, C77.1, C78.1, D26.C, J13.72, R64.2, R65.2, U25.8, U26.28, U26.30
3.3V13: C79.1, C82.1, C83.1, C84.1, D28.C, J14.72, R69.2, R70.2, U27.8, U28.28, U28.30
3.3V14: C85.1, C88.1, C89.1, C90.1, D30.C, J15.72, R74.2, R75.2, U29.8, U30.28, U30.30
3.3V15: C91.1, C94.1, C95.1, C96.1, D32.C, J16.72, R79.2, R80.2, U31.8, U32.28, U32.30
3.3V_EN: J1.4, U2.8
3.3V_EN1: J2.4, U4.8
3.3V_EN2: J3.4, U6.8
3.3V_EN3: J4.4, U8.8
3.3V_EN4: J5.4, U10.8
3.3V_EN5: J6.4, U12.8
3.3V_EN6: J7.4, U14.8
3.3V_EN7: J8.4, U16.8
3.3V_EN8: J9.4, U18.8
3.3V_EN9: J10.4, U20.8
3.3V_EN10: J11.4, U22.8
3.3V_EN11: J12.4, U24.8
3.3V_EN12: J13.4, U26.8
3.3V_EN13: J14.4, U28.8
3.3V_EN14: J15.4, U30.8
3.3V_EN15: J16.4, U32.8
!BOOT!: J1.11, R4.1, U2.23
!BOOT!1: J2.11, R9.1, U4.23
!BOOT!2: J3.11, R14.1, U6.23
!BOOT!3: J4.11, R19.1, U8.23
!BOOT!4: J5.11, R24.1, U10.23
!BOOT!5: J6.11, R29.1, U12.23
!BOOT!6: J7.11, R34.1, U14.23
!BOOT!7: J8.11, R39.1, U16.23
!BOOT!8: J9.11, R44.1, U18.23
!BOOT!9: J10.11, R49.1, U20.23
!BOOT!10: J11.11, R54.1, U22.23
!BOOT!11: J12.11, R59.1, U24.23
!BOOT!12: J13.11, R64.1, U26.23
!BOOT!13: J14.11, R69.1, U28.23
!BOOT!14: J15.11, R74.1, U30.23
!BOOT!15: J16.11, R79.1, U32.23
!RESET!: J1.6, R5.1, U2.40
!RESET!1: J2.6, R10.1, U4.40
!RESET!2: J3.6, R15.1, U6.40
!RESET!3: J4.6, R20.1, U8.40
!RESET!4: J5.6, R25.1, U10.40
!RESET!5: J6.6, R30.1, U12.40
!RESET!6: J7.6, R35.1, U14.40
!RESET!7: J8.6, R40.1, U16.40
!RESET!8: J9.6, R45.1, U18.40
!RESET!9: J10.6, R50.1, U20.40
!RESET!10: J11.6, R55.1, U22.40
!RESET!11: J12.6, R60.1, U24.40
!RESET!12: J13.6, R65.1, U26.40
!RESET!13: J14.6, R70.1, U28.40
!RESET!14: J15.6, R75.1, U30.40
!RESET!15: J16.6, R80.1, U32.40
ADC0: J1.34, U2.20
ADC1: J1.38, U2.21
ADC2: J2.34, U4.20
ADC3: J2.38, U4.21
ADC4: J3.34, U6.20
ADC5: J3.38, U6.21
ADC6: J4.34, U8.20
ADC7: J4.38, U8.21
ADC8: J5.34, U10.20
ADC9: J5.38, U10.21
ADC10: J6.34, U12.20
ADC11: J6.38, U12.21
ADC12: J7.34, U14.20
ADC13: J7.38, U14.21
ADC14: J8.34, U16.20
ADC15: J8.38, U16.21
ADC16: J9.34, U18.20
ADC17: J9.38, U18.21
ADC18: J10.34, U20.20
ADC19: J10.38, U20.21
ADC20: J11.34, U22.20
ADC21: J11.38, U22.21
ADC22: J12.34, U24.20
ADC23: J12.38, U24.21
ADC24: J13.34, U26.20
ADC25: J13.38, U26.21
ADC26: J14.34, U28.20
ADC27: J14.38, U28.21
ADC28: J15.34, U30.20
ADC29: J15.38, U30.21
ADC30: J16.34, U32.20
ADC31: J16.38, U32.21
BATT_VIN/1: J2.49, U4.14
BATT_VIN/2: J3.49, U6.14
BATT_VIN/3: J1.49, U2.14
BATT_VIN/4: J4.49, U8.14
BATT_VIN/5: J5.49, U10.14
BATT_VIN/6: J6.49, U12.14
BATT_VIN/7: J7.49, U14.14
BATT_VIN/8: J8.49, U16.14
BATT_VIN/9: J9.49, U18.14
BATT_VIN/10: J10.49, U20.14
BATT_VIN/11: J11.49, U22.14
BATT_VIN/12: J12.49, U24.14
BATT_VIN/13: J13.49, U26.14
BATT_VIN/14: J14.49, U28.14
BATT_VIN/15: J15.49, U30.14
BATT_VIN/16: J16.49, U32.14
CTS1: J1.15, U2.26
CTS2: J2.15, U4.26
CTS3: J3.15, U6.26
CTS4: J4.15, U8.26
CTS5: J5.15, U10.26
CTS6: J6.15, U12.26
CTS7: J7.15, U14.26
CTS8: J8.15, U16.26
CTS9: J9.15, U18.26
CTS10: J10.15, U20.26
CTS11: J11.15, U22.26
CTS12: J12.15, U24.26
CTS13: J13.15, U26.26
CTS14: J14.15, U28.26
CTS15: J15.15, U30.26
CTS16: J16.15, U32.26
D0: J1.10, U2.16
D1: J1.18, U2.25
D2: J2.10, U4.16
D3: J2.18, U4.25
D4: J3.10, U6.16
D5: J3.18, U6.25
D6: J4.10, U8.16
D7: J4.18, U8.25
D8: J5.10, U10.16
D9: J5.18, U10.25
D10: J6.10, U12.16
D11: J6.18, U12.25
D12: J7.10, U14.16
D13: J7.18, U14.25
D14: J8.10, U16.16
D15: J8.18, U16.25
D16: J9.10, U18.16
D17: J9.18, U18.25
D18: J10.10, U20.16
D19: J10.18, U20.25
D20: J11.10, U22.16
D21: J11.18, U22.25
D22: J12.10, U24.16
D23: J12.18, U24.25
D24: J13.10, U26.16
D25: J13.18, U26.25
D26: J14.10, U28.16
D27: J14.18, U28.25
D28: J15.10, U30.16
D29: J15.18, U30.25
D30: J16.10, U32.16
D31: J16.18, U32.25
FLASH_!CS!: U1.1, U2.29
FLASH_!CS!1: U3.1, U4.29
FLASH_!CS!2: U5.1, U6.29
FLASH_!CS!3: U7.1, U8.29
FLASH_!CS!4: U9.1, U10.29
FLASH_!CS!5: U11.1, U12.29
FLASH_!CS!6: U13.1, U14.29
FLASH_!CS!7: U15.1, U16.29
FLASH_!CS!8: U17.1, U18.29
FLASH_!CS!9: U19.1, U20.29
FLASH_!CS!10: U21.1, U22.29
FLASH_!CS!11: U23.1, U24.29
FLASH_!CS!12: U25.1, U26.29
FLASH_!CS!13: U27.1, U28.29
FLASH_!CS!14: U29.1, U30.29
FLASH_!CS!15: U31.1, U32.29
GND: C1.2, C2.1, C3.1, C4.2, C5.2, C6.2, D1.C, J1.1, J1.7, J1.33, J1.36, J1.39, J1.45, J1.75, J1.GND1, J1.GND2, J1.GND3, U1.4, U2.1, U2.2, U2.15, U2.33, U2.55
GND1: C7.2, C8.1, C9.1, C10.2, C11.2, C12.2, D3.C, J2.1, J2.7, J2.33, J2.36, J2.39, J2.45, J2.75, J2.GND1, J2.GND2, J2.GND3, U3.4, U4.1, U4.2, U4.15, U4.33, U4.55
GND2: C13.2, C14.1, C15.1, C16.2, C17.2, C18.2, D5.C, J3.1, J3.7, J3.33, J3.36, J3.39, J3.45, J3.75, J3.GND1, J3.GND2, J3.GND3, U5.4, U6.1, U6.2, U6.15, U6.33, U6.55
GND3: C19.2, C20.1, C21.1, C22.2, C23.2, C24.2, D7.C, J4.1, J4.7, J4.33, J4.36, J4.39, J4.45, J4.75, J4.GND1, J4.GND2, J4.GND3, U7.4, U8.1, U8.2, U8.15, U8.33, U8.55
GND4: C25.2, C26.1, C27.1, C28.2, C29.2, C30.2, D9.C, J5.1, J5.7, J5.33, J5.36, J5.39, J5.45, J5.75, J5.GND1, J5.GND2, J5.GND3, U9.4, U10.1, U10.2, U10.15, U10.33, U10.55
GND5: C31.2, C32.1, C33.1, C34.2, C35.2, C36.2, D11.C, J6.1, J6.7, J6.33, J6.36, J6.39, J6.45, J6.75, J6.GND1, J6.GND2, J6.GND3, U11.4, U12.1, U12.2, U12.15, U12.33, U12.55
GND6: C37.2, C38.1, C39.1, C40.2, C41.2, C42.2, D13.C, J7.1, J7.7, J7.33, J7.36, J7.39, J7.45, J7.75, J7.GND1, J7.GND2, J7.GND3, U13.4, U14.1, U14.2, U14.15, U14.33, U14.55
GND7: C43.2, C44.1, C45.1, C46.2, C47.2, C48.2, D15.C, J8.1, J8.7, J8.33, J8.36, J8.39, J8.45, J8.75, J8.GND1, J8.GND2, J8.GND3, U15.4, U16.1, U16.2, U16.15, U16.33, U16.55
GND8: C49.2, C50.1, C51.1, C52.2, C53.2, C54.2, D17.C, J9.1, J9.7, J9.33, J9.36, J9.39, J9.45, J9.75, J9.GND1, J9.GND2, J9.GND3, U17.4, U18.1, U18.2, U18.15, U18.33, U18.55
GND9: C55.2, C56.1, C57.1, C58.2, C59.2, C60.2, D19.C, J10.1, J10.7, J10.33, J10.36, J10.39, J10.45, J10.75, J10.GND1, J10.GND2, J10.GND3, U19.4, U20.1, U20.2, U20.15, U20.33, U20.55
GND10: C61.2, C62.1, C63.1, C64.2, C65.2, C66.2, D21.C, J11.1, J11.7, J11.33, J11.36, J11.39, J11.45, J11.75, J11.GND1, J11.GND2, J11.GND3, U21.4, U22.1, U22.2, U22.15, U22.33, U22.55
GND11: C67.2, C68.1, C69.1, C70.2, C71.2, C72.2, D23.C, J12.1, J12.7, J12.33, J12.36, J12.39, J12.45, J12.75, J12.GND1, J12.GND2, J12.GND3, U23.4, U24.1, U24.2, U24.15, U24.33, U24.55
GND12: C73.2, C74.1, C75.1, C76.2, C77.2, C78.2, D25.C, J13.1, J13.7, J13.33, J13.36, J13.39, J13.45, J13.75, J13.GND1, J13.GND2, J13.GND3, U25.4, U26.1, U26.2, U26.15, U26.33, U26.55
GND13: C79.2, C80.1, C81.1, C82.2, C83.2, C84.2, D27.C, J14.1, J14.7, J14.33, J14.36, J14.39, J14.45, J14.75, J14.GND1, J14.GND2, J14.GND3, U27.4, U28.1, U28.2, U28.15, U28.33, U28.55
GND14: C85.2, C86.1, C87.1, C88.2, C89.2, C90.2, D29.C, J15.1, J15.7, J15.33, J15.36, J15.39, J15.45, J15.75, J15.GND1, J15.GND2, J15.GND3, U29.4, U30.1, U30.2, U30.15, U30.33, U30.55
GND15: C91.2, C92.1, C93.1, C94.2, C95.2, C96.2, D31.C, J16.1, J16.7, J16.33, J16.36, J16.39, J16.45, J16.75, J16.GND1, J16.GND2, J16.GND3, U31.4, U32.1, U32.2, U32.15, U32.33, U32.55
GPIO0/ADC1: J2.40, U4.10
GPIO0/ADC2: J1.40, U2.10
GPIO0/ADC3: J3.40, U6.10
GPIO0/ADC4: J4.40, U8.10
GPIO0/ADC5: J5.40, U10.10
GPIO0/ADC6: J6.40, U12.10
GPIO0/ADC7: J7.40, U14.10
GPIO0/ADC8: J8.40, U16.10
GPIO0/ADC9: J9.40, U18.10
GPIO0/ADC10: J10.40, U20.10
GPIO0/ADC11: J11.40, U22.10
GPIO0/ADC12: J12.40, U24.10
GPIO0/ADC13: J13.40, U26.10
GPIO0/ADC14: J14.40, U28.10
GPIO0/ADC15: J15.40, U30.10
GPIO0/ADC16: J16.40, U32.10
GPIO1: J2.73, U4.41
GPIO1/ADC1: J2.42, U4.9
GPIO1/ADC2: J3.42, U6.9
GPIO1/ADC3: J1.42, U2.9
GPIO1/ADC4: J4.42, U8.9
GPIO1/ADC5: J5.42, U10.9
GPIO1/ADC6: J6.42, U12.9
GPIO1/ADC7: J7.42, U14.9
GPIO1/ADC8: J8.42, U16.9
GPIO1/ADC9: J9.42, U18.9
GPIO1/ADC10: J10.42, U20.9
GPIO1/ADC11: J11.42, U22.9
GPIO1/ADC12: J12.42, U24.9
GPIO1/ADC13: J13.42, U26.9
GPIO1/ADC14: J14.42, U28.9
GPIO1/ADC15: J15.42, U30.9
GPIO1/ADC16: J16.42, U32.9
GPIO2: J1.44, U2.6
GPIO3: J1.46, U2.5
GPIO4: J1.48, U2.4
GPIO5: J1.73, U2.41
GPIO6: J1.71, U2.57
GPIO7: J1.69, U2.56
GPIO8: J1.67, U2.7
GPIO9: J2.69, U4.56
GPIO9/NFC1: J1.65, U2.52
GPIO9/NFC2: J2.65, U4.52
GPIO9/NFC3: J3.65, U6.52
GPIO9/NFC4: J4.65, U8.52
GPIO9/NFC5: J5.65, U10.52
GPIO9/NFC6: J6.65, U12.52
GPIO9/NFC7: J7.65, U14.52
GPIO9/NFC8: J8.65, U16.52
GPIO9/NFC9: J9.65, U18.52
GPIO9/NFC10: J10.65, U20.52
GPIO9/NFC11: J11.65, U22.52
GPIO9/NFC12: J12.65, U24.52
GPIO9/NFC13: J13.65, U26.52
GPIO9/NFC14: J14.65, U28.52
GPIO9/NFC15: J15.65, U30.52
GPIO9/NFC16: J16.65, U32.52
GPIO10: J2.71, U4.57
GPIO10/NFC1: J2.63, U4.54
GPIO10/NFC2: J1.63, U2.54
GPIO10/NFC3: J3.63, U6.54
GPIO10/NFC4: J4.63, U8.54
GPIO10/NFC5: J5.63, U10.54
GPIO10/NFC6: J6.63, U12.54
GPIO10/NFC7: J7.63, U14.54
GPIO10/NFC8: J8.63, U16.54
GPIO10/NFC9: J9.63, U18.54
GPIO10/NFC10: J10.63, U20.54
GPIO10/NFC11: J11.63, U22.54
GPIO10/NFC12: J12.63, U24.54
GPIO10/NFC13: J13.63, U26.54
GPIO10/NFC14: J14.63, U28.54
GPIO10/NFC15: J15.63, U30.54
GPIO10/NFC16: J16.63, U32.54
GPIO11: J2.46, U4.5
GPIO12: J2.44, U4.6
GPIO13: J2.48, U4.4
GPIO14: J2.67, U4.7
GPIO15: J3.73, U6.41
GPIO16: J3.69, U6.56
GPIO17: J3.71, U6.57
GPIO18: J3.46, U6.5
GPIO19: J3.44, U6.6
GPIO20: J3.48, U6.4
GPIO21: J3.67, U6.7
GPIO22: J4.73, U8.41
GPIO23: J4.69, U8.56
GPIO24: J4.71, U8.57
GPIO25: J4.46, U8.5
GPIO26: J4.44, U8.6
GPIO27: J4.48, U8.4
GPIO28: J4.67, U8.7
GPIO29: J5.73, U10.41
GPIO30: J5.69, U10.56
GPIO31: J5.71, U10.57
GPIO32: J5.46, U10.5
GPIO33: J5.44, U10.6
GPIO34: J5.48, U10.4
GPIO35: J5.67, U10.7
GPIO36: J6.73, U12.41
GPIO37: J6.69, U12.56
GPIO38: J6.71, U12.57
GPIO39: J6.46, U12.5
GPIO40: J6.44, U12.6
GPIO41: J6.48, U12.4
GPIO42: J6.67, U12.7
GPIO43: J7.73, U14.41
GPIO44: J7.69, U14.56
GPIO45: J7.71, U14.57
GPIO46: J7.46, U14.5
GPIO47: J7.44, U14.6
GPIO48: J7.48, U14.4
GPIO49: J7.67, U14.7
GPIO50: J8.73, U16.41
GPIO51: J8.69, U16.56
GPIO52: J8.71, U16.57
GPIO53: J8.46, U16.5
GPIO54: J8.44, U16.6
GPIO55: J8.48, U16.4
GPIO56: J8.67, U16.7
GPIO57: J9.73, U18.41
GPIO58: J9.69, U18.56
GPIO59: J9.71, U18.57
GPIO60: J9.46, U18.5
GPIO61: J9.44, U18.6
GPIO62: J9.48, U18.4
GPIO63: J9.67, U18.7
GPIO64: J10.73, U20.41
GPIO65: J10.69, U20.56
GPIO66: J10.71, U20.57
GPIO67: J10.46, U20.5
GPIO68: J10.44, U20.6
GPIO69: J10.48, U20.4
GPIO70: J10.67, U20.7
GPIO71: J11.73, U22.41
GPIO72: J11.69, U22.56
GPIO73: J11.71, U22.57
GPIO74: J11.46, U22.5
GPIO75: J11.44, U22.6
GPIO76: J11.48, U22.4
GPIO77: J11.67, U22.7
GPIO78: J12.73, U24.41
GPIO79: J12.69, U24.56
GPIO80: J12.71, U24.57
GPIO81: J12.46, U24.5
GPIO82: J12.44, U24.6
GPIO83: J12.48, U24.4
GPIO84: J12.67, U24.7
GPIO85: J13.73, U26.41
GPIO86: J13.69, U26.56
GPIO87: J13.71, U26.57
GPIO88: J13.46, U26.5
GPIO89: J13.44, U26.6
GPIO90: J13.48, U26.4
GPIO91: J13.67, U26.7
GPIO92: J14.73, U28.41
GPIO93: J14.69, U28.56
GPIO94: J14.71, U28.57
GPIO95: J14.46, U28.5
GPIO96: J14.44, U28.6
GPIO97: J14.48, U28.4
GPIO98: J14.67, U28.7
GPIO99: J15.73, U30.41
GPIO100: J15.69, U30.56
GPIO101: J15.71, U30.57
GPIO102: J15.46, U30.5
GPIO103: J15.44, U30.6
GPIO104: J15.48, U30.4
GPIO105: J15.67, U30.7
GPIO106: J16.73, U32.41
GPIO107: J16.69, U32.56
GPIO108: J16.71, U32.57
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

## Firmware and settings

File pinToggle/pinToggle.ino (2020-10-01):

/*
 * Toggle example
 */
 
void setup() {
  pinMode(G0, OUTPUT);
  pinMode(G1, OUTPUT);
  pinMode(G2, OUTPUT);
  pinMode(G3, OUTPUT);
  pinMode(G4, OUTPUT);
  pinMode(G5, OUTPUT);
  pinMode(G6, OUTPUT);
  pinMode(G7, OUTPUT);
  pinMode(LED_BUILTIN, OUTPUT);
  pinMode(PIN_WIRE_INT, OUTPUT);
}

void loop() {
  // put your main code here, to run repeatedly:
  digitalWrite(G0, HIGH);
  digitalWrite(G1, HIGH);
  digitalWrite(G2, HIGH);
  digitalWrite(G3, HIGH);
  digitalWrite(G4, HIGH);
  digitalWrite(G5, HIGH);
  digitalWrite(G6, HIGH);
  digitalWrite(G7, HIGH);
  digitalWrite(LED_BUILTIN, HIGH);
  digitalWrite(PIN_WIRE_INT, HIGH);
  delay(1000);
  digitalWrite(G0, LOW);
  digitalWrite(G1, LOW);
  digitalWrite(G2, LOW);
  digitalWrite(G3, LOW);
  digitalWrite(G4, LOW);
  digitalWrite(G5, LOW);
  digitalWrite(G6, LOW);
  digitalWrite(G7, LOW);
  digitalWrite(LED_BUILTIN, LOW);
  digitalWrite(PIN_WIRE_INT, LOW);
  delay(1000);
}

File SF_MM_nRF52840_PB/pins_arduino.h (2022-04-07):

#pragma once
#include <stdint.h>
#include <macros.h>

#ifndef __PINS_ARDUINO__
#define __PINS_ARDUINO__

#define ANALOG_CONFIG

/* Analog reference options
 * Different possibilities available combining Reference and Gain
 */
enum _AnalogReferenceMode
{
  AR_VDD,         // 3.3 V
  AR_INTERNAL,    // 0.6 V
  AR_INTERNAL1V2, // 1.2 V
  AR_INTERNAL2V4  // 2.4 V
};

/* Analog acquisition time options */
enum _AnalogAcquisitionTime
{
  AT_3_US,
  AT_5_US,
  AT_10_US, // Default value
  AT_15_US,
  AT_20_US,
  AT_40_US
};

// Frequency of the board main oscillator
#define VARIANT_MAINOSC (32768ul)

// Master clock frequency
#define VARIANT_MCK (64000000ul)

// Pins
// ----
// Number of pins defined in PinDescription array
#ifdef __cplusplus
extern "C" unsigned int PINCOUNT_fn();
#endif
#define PINS_COUNT (PINCOUNT_fn())
#define NUM_DIGITAL_PINS (48u)
#define NUM_ANALOG_INPUTS (6u)
#define NUM_ANALOG_OUTPUTS (0u)

extern PinName digitalPinToPinName(pin_size_t P);       // add paulvha

// LEDs
// ----
#define PIN_LED (13u)
#define LED_BUILTIN PIN_LED

// Analog pins
// -----------
#define PIN_A0 (4u)
#define PIN_A1 (5u)
#define PIN_A2 (29u)
#define PIN_A3 (28u)
#define PIN_A4 (30u)
#define PIN_A5 (31u)
static const uint8_t A0 = PIN_A0;
static const uint8_t A1 = PIN_A1;
static const uint8_t A2 = PIN_A2;
static const uint8_t A3 = PIN_A3;
static const uint8_t A4 = PIN_A4;
static const uint8_t A5 = PIN_A5;
#define PIN_PWM0 (6u)
#define PIN_PWM1 (16u)
static const uint8_t PWM0 = PIN_PWM0;
static const uint8_t PWM1 = PIN_PWM1;
#define PIN_BATTVIN3 (30u)
static const uint8_t BATTVIN3 = PIN_BATTVIN3;
#define ADC_RESOLUTION 12

// Digital pins
// -----------
#define D0 27
#define D1 40
#define G0 29
#define G1 3
#define G2 45
#define G3 44
#define G4 43
#define G5 17
#define G6 38
#define G7 36
#define G8 46
#define G9 9
#define G10 10

/*
 * Serial interfaces
 */
// Serial (EDBG)
#define PIN_SERIAL_RX1 (42ul)
#define PIN_SERIAL_TX1 (35ul)
//For serial flow control, uncomment lines 189 and 190
#define PIN_SERIAL_RTS1 (34ul)
#define PIN_SERIAL_CTS1 (41ul)

#define PIN_SERIAL_RX2 (37ul)
#define PIN_SERIAL_TX2 (39ul)

// SPI
#define PIN_SPI_CIPO (2u)
#define PIN_SPI_COPI (31u)
#define PIN_SPI_SCK (28u)
#define PIN_SPI_SS (20u)

// //NOTE: this is for onboard flash IC
// #define PIN_SPI_CIPO (21u)
// #define PIN_SPI_COPI (14u)
// #define PIN_SPI_SCK (19u)
// #define PIN_SPI_SS (12u)

static const uint8_t SS = PIN_SPI_SS;
static const uint8_t MOSI = PIN_SPI_COPI;
static const uint8_t MISO = PIN_SPI_CIPO;
static const uint8_t SCK = PIN_SPI_SCK;

#define PIN_SPI_CIPO1 (21u)
#define PIN_SPI_COPI1 (14u)
#define PIN_SPI_SCK1 (19u)
#define PIN_SPI_SS1 (32u)

static const uint8_t SS1 = PIN_SPI_SS1;
static const uint8_t MOSI1 = PIN_SPI_COPI1;
static const uint8_t MISO1 = PIN_SPI_CIPO1;
static const uint8_t SCK1 = PIN_SPI_SCK1;

#define PIN_QSPI_SCK 19
#define PIN_QSPI_CS 14
#define PIN_QSPI_IO0 21
#define PIN_QSPI_IO1 22
#define PIN_QSPI_IO2 23
#define PIN_QSPI_IO3 32

// Wire
#define PIN_WIRE_SDA (8u)
#define PIN_WIRE_SCL (11u)
#define PIN_WIRE_INT (15u)

#define PIN_WIRE_SDA1 (33u)
#define PIN_WIRE_SCL1 (24u)

// PDM Interfaces
// ---------------
#define PIN_PDM_PWR (46)
#define PIN_PDM_CLK (25)
#define PIN_PDM_DIN (26)

// These serial port names are intended to allow libraries and architecture-neutral
// sketches to automatically default to the correct port name for a particular type
// of use.  For example, a GPS module would normally connect to SERIAL_PORT_HARDWARE_OPEN,
// the first hardware serial port whose RX/TX pins are not dedicated to another use.
//
// SERIAL_PORT_MONITOR        Port which normally prints to the Arduino Serial Monitor
//
// SERIAL_PORT_USBVIRTUAL     Port which is USB virtual serial
//
// SERIAL_PORT_LINUXBRIDGE    Port which connects to a Linux system via Bridge library
//
// SERIAL_PORT_HARDWARE       Hardware serial port, physical RX & TX pins.
//
// SERIAL_PORT_HARDWARE_OPEN  Hardware serial ports which are open for use.  Their RX & TX
//                            pins are NOT connected to anything by default.
#define SERIAL_PORT_USBVIRTUAL SerialUSB
#define SERIAL_PORT_MONITOR SerialUSB
#define SERIAL_PORT_HARDWARE Serial1
#define SERIAL_PORT_HARDWARE_OPEN Serial1

// Mbed specific defines
#define SERIAL_HOWMANY 2
#define SERIAL1_TX (digitalPinToPinName(PIN_SERIAL_TX1))
#define SERIAL1_RX (digitalPinToPinName(PIN_SERIAL_RX1))
//Uncomment the following two lines if you want to implement serial flow control
// #define SERIAL1_RTS (digitalPinToPinName(PIN_SERIAL_RTS1))
// #define SERIAL1_CTS (digitalPinToPinName(PIN_SERIAL_CTS1))
#define SERIAL2_TX (digitalPinToPinName(PIN_SERIAL_TX2))
#define SERIAL2_RX (digitalPinToPinName(PIN_SERIAL_RX2))

#define SERIAL_CDC 1
#define HAS_UNIQUE_ISERIAL_DESCRIPTOR
#define BOARD_VENDORID 0x2341
#define BOARD_PRODUCTID 0x805a
#define BOARD_NAME "Nano 33 BLE"

#define DFU_MAGIC_SERIAL_ONLY_RESET 0xb0

#define WIRE_HOWMANY 2
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

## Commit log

2020-06-04 Initial commit
    Copied Artemis PB Eagle files into repo as a starting point.
    [MicroMod-Artemis-ProcessorBoard.brd, MicroMod-Artemis-ProcessorBoard.sch]
2020-06-04 Renamed eagle files appropriately
    [MicroMod_Processor_Board-nRF52840.brd, MicroMod_Processor_Board-nRF52840.sch]
2020-06-09 Ripped up old traces
    [MicroMod_Processor_Board-nRF52840.brd, MicroMod_Processor_Board-nRF52840.sch]
2020-06-09 Removed some dividing lines in schematic
    [MicroMod_Processor_Board-nRF52840.brd, MicroMod_Processor_Board-nRF52840.sch]
2020-06-17 Determined nets of some nRF pins.
    [MicroMod_Processor_Board-nRF52840.brd, MicroMod_Processor_Board-nRF52840.sch]
2020-06-19 Working on schematic
    [MicroMod_Processor_Board-nRF52840.brd, MicroMod_Processor_Board-nRF52840.sch]
2020-06-19 Preliminary schematic finished
    [MicroMod_Processor_Board-nRF52840.brd, MicroMod_Processor_Board-nRF52840.sch]
2020-06-23 Finished preliminary schematic
    [MicroMod_Processor_Board-nRF52840.brd, MicroMod_Processor_Board-nRF52840.sch]
2020-06-24 Preliminary layout of PB
    [MicroMod_Processor_Board-nRF52840.brd]
2020-07-14 Started routing
    [MicroMod_Processor_Board-nRF52840.brd]
2020-07-23 Placed silk screen
    [MicroMod_Processor_Board-nRF52840.brd, MicroMod_Processor_Board-nRF52840.sch]
2020-07-25 Implemented changes from first design review
    [MicroMod_Processor_Board-nRF52840.brd, MicroMod_Processor_Board-nRF52840.sch]
2020-07-27 Going over check list
    [MicroMod_Processor_Board-nRF52840.brd, MicroMod_Processor_Board-nRF52840.sch]
2020-07-29 Changes from QC Double Check
    [MicroMod_Processor_Board-nRF52840.brd, MicroMod_Processor_Board-nRF52840.sch]
2020-07-30 Added more GND vias and made top polygon isolate larger
    [MicroMod_Processor_Board-nRF52840.brd, MicroMod_Processor_Board-nRF52840.sch]
2020-07-30 Firt panelization and cam generation
    [MicroMod_Processor_Board-nRF52840-Panel.GBL, MicroMod_Processor_Board-nRF52840-Panel.GBO, MicroMod_Processor_Board-nRF52840-Panel.GBP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]
2020-09-09 Adding temp folder that holds current variant files
2020-09-24 New variant files for arduino core
2020-10-01 Schematic updated post-proto testing
    Changes made: https://docs.google.com/document/d/1057ZJf50zAkChxiBm4WqtqCuvZdJMlmnGmuK_T1RHvQ/edit
    [MicroMod_Processor_Board-nRF52840.brd, MicroMod_Processor_Board-nRF52840.sch]
2020-10-01 Routing for v10
    [MicroMod_Processor_Board-nRF52840.brd, MicroMod_Processor_Board-nRF52840.sch]
2020-10-02 Design review and checklist changes
    [MicroMod_Processor_Board-nRF52840.brd, MicroMod_Processor_Board-nRF52840.sch]
2020-10-07 Update ble_temp.ino
    Created BLE example demo/use case for nRF PB. TX BME280 temperature measurements.
2020-10-07 Update PROD_IDs for 27 ohm resistors
    [MicroMod_Processor_Board-nRF52840.brd, MicroMod_Processor_Board-nRF52840.sch]
2020-10-08 Re-panelized for v10
    [MicroMod_Processor_Board-nRF52840-Panel.brd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]
2020-10-13 Update MicroMod_Processor_Board-nRF52840.zip
    New board files for v10
2020-11-05 Analog pin defs
2020-11-06 Updated variant files for new version of arduino core
    [MicroMod_Processor_Board-nRF52840.brd, MicroMod_Processor_Board-nRF52840.sch]
2020-11-09 Renamed variant files and updated boards.txt
2021-01-14 Update README.md
    Fix folder name and description for Variant Files. Add link to MicroMod landing page.
2022-04-07 Updates for "Arduino Mbed OS Nano Boards" v3.0.1
2022-06-09 Remove excess variant files.
    From now on, we want customers to duplicate the "ARDUINO_NANO33BLE" folder of the arduino board package, rename it to "SF_MM_nRF52840_PB", and only copy over the MM specific pin definition files. Thi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

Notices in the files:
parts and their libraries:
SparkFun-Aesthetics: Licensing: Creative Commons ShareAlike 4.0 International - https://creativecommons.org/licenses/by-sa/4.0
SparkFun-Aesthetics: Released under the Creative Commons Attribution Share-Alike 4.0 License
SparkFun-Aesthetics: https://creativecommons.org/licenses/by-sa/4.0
